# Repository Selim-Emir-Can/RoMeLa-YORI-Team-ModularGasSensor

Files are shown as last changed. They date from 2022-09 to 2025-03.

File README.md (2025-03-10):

# Modular Gas Sensor

## Table of Contents
* [Summary](#Summary)
* [Setup](#Setup)
* [Installation](#Installation)

## Summary
The Modular Gas Sensor uses 17 gas sensors that consist of:
<li>DFRobot CO2 Sensor V1.2</li>
<li>DHT22 Temperature and Humidity Sensor</li>
<li>DFRobot Ozone Sensor (0-10ppm) v1.0 (I2C)</li>
<li>DFRobot Gravity Formaldehyde (HCHO) Sensor (DAC)</li>
<li>SGP40 VOC (Volatile Organic Compound) Sensor (I2C)</li>
<li>Figaro TGS2611 Air Contaminants Sensor with drive board module</li>
<li>CJMCU-1100 MS-1100 VOC Gas Sensor Module Formaldehyde Benzene Gas Induction</li>
<li>MH-Z14 NDIR CO2 Infrared Sensor Module MH-Z14A Carbon Dioxide Sensor for CO2 (0-5000ppm, Serial Spot PWM)</li>
<li>MQ-2, MQ-3, MQ-4, MQ-5, MQ-6, MQ-7, MQ-8, MQ-9, MQ-135 Smoke Detection liquefied Methane Gas Sensor Module</li>

The data gathered from the sensors listed above during the cooking process will constitute a chemical signature which will be used to analyze the cumulative gas concentration with respect to time. The gas sensor shell stores these sensors, and the hardware which extracts and processes data which includes a custom PCB and a Raspberry Pi Zero 2W. All components of the gas sensor shell are modular, meaning it can be modified to store any amount of gas sensors if the necessary parts are made. More visual explanation can be found [here](https://selim-e-can.github.io/GasSensor.html).

## Setup

### SGP40 VOC Sensor and DFRobot Ozone Sensor (0-10ppm) v1.0
* enable I2C connection from settings using sudo raspi-config
* connect SDA to GPIO 2, SCL to GPIO 3

### DHT22 Digital Temperature and Humidity Sensor
* connect GPIO 4 pin to DAT pin

Note: The temperature sensor does not work according to specification if measurements are taken within a time interval less then 3 seconds.

### Other Gas Sensors
* connect rest of the gas sensors to MCP3008 ADC Converter channels

### First MCP3008 ADC Converter
* connect the GPIO 18 pin to Clock (CLK)
* connect the GPIO 23 pin to Master Input Slave Output (MISO)
* connect the GPIO 24 pin to Master Output Slave Input (MOSI)
* connect the GPIO 25 pin to Chip Select (CS)

### Second MCP3008 ADC Converter
* connect the GPIO 18 pin to Clock (CLK)
* connect the GPIO 23 pin to Master Input Slave Output (MISO)
* connect the GPIO 24 pin to Master Output Slave Input (MOSI)
* connect the GPIO 26 pin to Chip Select (CS)

## Installation
### Adafruit_GPIO Library
sudo apt-get update <br />
sudo apt-get install build-essential python-pip python-dev python-smbus git <br />
git clone https://github.com/adafruit/Adafruit_Python_GPIO.git <br />
cd Adafruit_Python_GPIO <br />
sudo python setup.py install <br />

### Adafruit_MCP3008 Library
sudo apt-get update <br />
sudo apt-get install build-essential python-dev python-smbus git <br />
cd ~ <br />
git clone https://github.com/adafruit/Adafruit_Python_MCP3008.git <br />
cd Adafruit_Python_MCP3008 <br />
sudo python setup.py install <br />

### DFRobot_Ozone Library
sudo apt-get update <br />
sudo apt-get upgrade <br />
git clone https://github.com/DFRobot/DFRobot_OzoneSensor <br />

### Adafruit_DHT Library
sudo pip3 install Adafruit_DHT

### smbus Library
sudo apt-get install python-smbus

### bcm2835 Library
wget http://www.airspayce.com/mikem/bcm2835/bcm2835-1.60.tar.gz <br />
tar zxvf bcm2835-1.60.tar.gz <br />
cd bcm2835-1.60/ <br />
sudo ./configure <br />
sudo make <br />
sudo make check <br />
sudo make install <br />

### wiringpi Library
sudo apt-get install wiringpi <br />
cd /tmp <br />
wget https://project-downloads.drogon.net/wiringpi-latest.deb <br />
sudo dpkg -i wiringpi-latest.deb <br />
gpio -v <br />

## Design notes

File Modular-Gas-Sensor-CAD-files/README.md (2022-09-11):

# Modular Gas Sensor

## Table of Contents
* [Summary](#Summary)
* [Setup](#Setup)

## Summary
Modular Gas Sensor uses 17 gas sensors within 4 layers:

 #### Layer 1 (M1 Chamber)
 <li>Flying Fish MQ-5 Sensor</li>
 <li>Flying Fish MQ-6 Sensor</li>
 <li>Flying Fish MQ-8 Sensor</li>
 <li>Flying Fish MQ-9 Sensor</li>
 <li>Flying Fish MQ-135 Sensor</li>
 
 #### Layer 2 (M2 Chamber)
 <li>Flying Fish MQ-2 Sensor</li>
 <li>Flying Fish MQ-3 Sensor</li>
 <li>Flying Fish MQ-4 Sensor</li>
 <li>Flying Fish MQ-7 Sensor</li>
 <li>Figaro TGS2611 Air Contaminants Sensor with drive board module</li>

 #### Layer 3 (M3 Chamber)
 
 <li>DHT22 Temperature and Humidity Sensor</li>
 <li>DFRobot CO2 Sensor V1.2</li>
 <li>MH-Z14 NDIR CO2 Infrared Sensor Module MH-Z14A Carbon Dioxide Sensor for CO2 (0-5000ppm, Serial Spot PWM)</li>
 <li>CJMCU-1100 MS-1100 VOC Gas Sensor Module Formaldehyde Benzene Gas Induction</li>

 #### Layer 4 (M4 Chamber)
 <li>DFRobot Ozone Sensor (0-10ppm) v1.0 (I2C)</li>
 <li>DFRobot Gravity Formaldehyde (HCHO) Sensor (DAC)</li>
 <li>SGP40 VOC (Volatile Organic Compound) Sensor (I2C)</li>

## Setup
For 3D printing a nozzle with a 6mm diameter was used at 30% infill for all parts. [Flexible coolant legs](https://www.digikey.com/en/products/detail/sparkfun-electronics/TOL-12783/5824155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), the [LCD Display](https://www.amazon.com/JANSANE-Arduino-Display-Interface-Raspberry/dp/B07D83DY17), and the [switch](https://www.amazon.com/gp/product/B01N2U8PK0/ref=ppx_yo_dt_b_search_asin_title?ie=UTF8&psc=1&pldnSite=1), and [buttons](https://www.amazon.com/gp/product/B06XF6PT9L/ref=ppx_yo_dt_b_search_asin_title?ie=UTF8&psc=1&pldnSite=1) that will be installed on the top cap were bought.

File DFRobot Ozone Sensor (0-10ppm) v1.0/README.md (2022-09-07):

# DFRobot Ozone Sensor (0-10ppm) v1.0

## Table of Contents
* [Summary](#Summary)
* [Setup](#Setup)
* [Installation](#Installation)

## Summary
The DFRobot Ozone Sensor (0-10ppm) v1.0 has a VCC pin, GND pin, SDA (Serial Data) pin, SCL (Serial Clock) pin and transmits data to the Raspberry Pi Zero 2W through the I2C communication protocol.

* DFRobot_Ozone.py defines the basic structure of the DFRobot_Ozone class, the implementation of the basic methods.
* get_ozone_data.py reads ozone concentration of one part per billion (PPB) using UART mode.

More documentation can be found [here](https://wiki.dfrobot.com/Gravity_IIC_Ozone_Sensor_(0-10ppm)%20SKU_SEN0321).

## Setup
* enable I2C connection from settings using sudo raspi-config
* connect SDA to GPIO 2, SCL to GPIO 3

## Installation
get_ozone_data.py uses the DFRobot_Ozone library which can be downloaded using:

### DFRobot_Ozone Library
sudo apt-get update <br />
sudo apt-get upgrade <br />
git clone https://github.com/DFRobot/DFRobot_OzoneSensor <br />

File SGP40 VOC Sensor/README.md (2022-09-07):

# SPG40 VOC (Volatile Organic Compound) Sensor

## Table of Contents
* [Summary](#Summary)
* [Setup](#Setup)
* [Installation](#Installation)

## Summary
SPG40 VOC Sensor has a VCC pin, GND pin, SDA (Serial Data) pin, SCL (Serial Clock) pin and transmits data to the Raspberry Pi Zero 2W through the I2C communication protocol. The SGP40.py file defines the basic structure of the SGP40 class, the implementation of the basic methods and prints. More documentation can be found [here](https://www.waveshare.com/wiki/SGP40_VOC_Sensor).

## Setup
* enable I2C connection from settings using sudo raspi-config
* connect SDA to GPIO 2, SCL to GPIO 3

## Installation
SGP40.py uses the smbus, bcm2835, and wiringpi libraries which can be downloaded using:

### smbus Library
sudo apt-get install python-smbus

### bcm2835 Library
wget http://www.airspayce.com/mikem/bcm2835/bcm2835-1.60.tar.gz <br />
tar zxvf bcm2835-1.60.tar.gz <br />
cd bcm2835-1.60/ <br />
sudo ./configure <br />
sudo make <br />
sudo make check <br />
sudo make install <br />

### wiringpi Library
sudo apt-get install wiringpi <br />
cd /tmp <br />
wget https://project-downloads.drogon.net/wiringpi-latest.deb <br />
sudo dpkg -i wiringpi-latest.deb <br />
gpio -v <br />

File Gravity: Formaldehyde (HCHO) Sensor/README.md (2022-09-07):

# Gravity: Formaldehyde (HCHO) Sensor

## Table of Contents
* [Summary](#Summary)
* [Setup](#Setup)
* [Installation](#Installation)

## Summary
The Gravity: Formaldehyde (HCHO) Sensor has a VCC pin, GND pin, and a data pin. The sensor has a DAC mode and a UART mode. Setting the Formaldehyde (HCHO) Sensor to DAC mode, using an MCP3008 ADC converter, a Raspberry Pi Zero 2W, and DFRobotHCHOSensor.py voltage data corrolated to ozone concentration can be displayed in real time. More documentation can be found [here](https://www.dfrobot.com/product-1574.html).

## Setup

### MCP3008 ADC Converter
* connect the GPIO 18 pin to Clock (CLK)
* connect the GPIO 23 pin to Master Input Slave Output (MISO)
* connect the GPIO 24 pin to Master Output Slave Input (MOSI)
* connect the GPIO 25 pin to Chip Select (CS)
* connect the data pin to Channel 0 input

## Installation
DFRobotHCHOSensor.py file uses the Adafruit_GPIO and Adafruit_MCP3008 libraries which can be downloaded using:

### Adafruit_GPIO Library
sudo apt-get update <br />
sudo apt-get install build-essential python-pip python-dev python-smbus git <br />
git clone https://github.com/adafruit/Adafruit_Python_GPIO.git <br />
cd Adafruit_Python_GPIO <br />
sudo python setup.py install <br />

### Adafruit_MCP3008 Library
sudo apt-get update <br />
sudo apt-get install build-essential python-dev python-smbus git <br />
cd ~ <br />
git clone https://github.com/adafruit/Adafruit_Python_MCP3008.git <br />
cd Adafruit_Python_MCP3008 <br />
sudo python setup.py install <br />

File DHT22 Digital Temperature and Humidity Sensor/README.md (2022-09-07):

# DHT22 Digital Temperature and Humidity Sensor

## Table of Contents
* [Summary](#Summary)
* [Setup](#Setup)
* [Installation](#Installation)

## Summary
The DHT22 Digital Temperature and Humidity Sensor has a DAT (Data) pin, a VCC pin, and a GND pin.
Temp-sensor.py file prints the temperature and humidity readings to the terminal every 3 seconds.
More documentation can be found [here](https://www.sparkfun.com/datasheets/Sensors/Temperature/DHT22.pdf).

## Setup
* connect GPIO 4 pin to DAT pin

Note: The temperature sensor does not work according to specification if measurements are taken within a time interval less then 3 seconds.

## Installation
Temp-sensor.py file uses the Adafruit_DHT library which can be downloaded using:

sudo pip3 install Adafruit_DHT

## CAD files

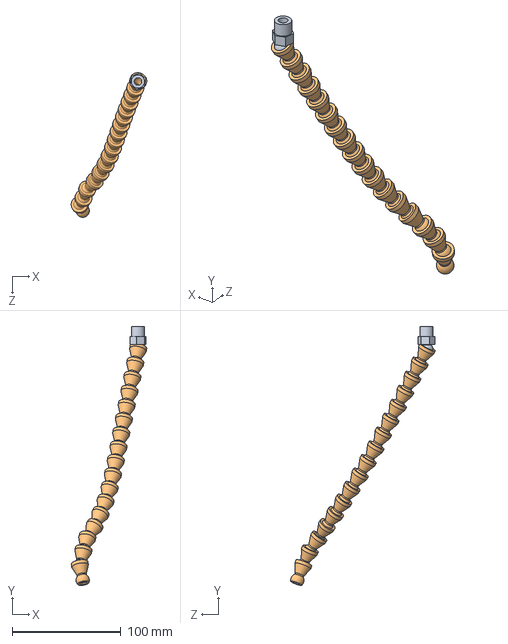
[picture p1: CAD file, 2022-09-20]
Modular-Gas-Sensor-CAD-files/Flexible coolant.SLDASM
69.7 x 238.7 x 133.4 mm
Flexible coolant conexion
Flexible coolant x 17

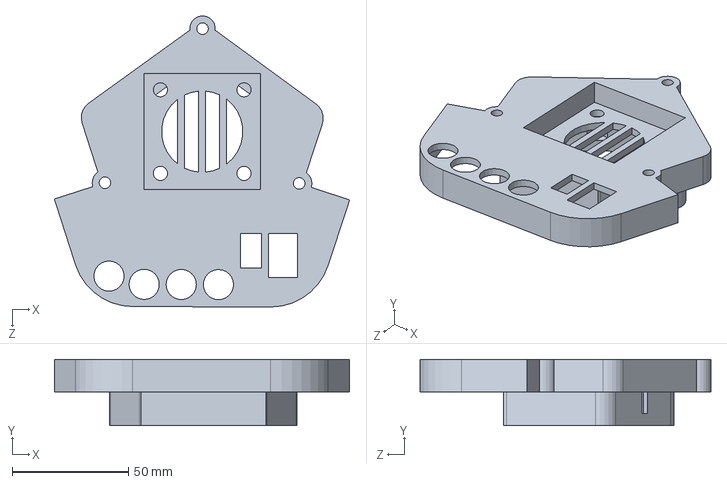
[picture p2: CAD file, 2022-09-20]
Modular-Gas-Sensor-CAD-files/topCap.SLDPRT
127.2 x 28.4 x 125.3 mm

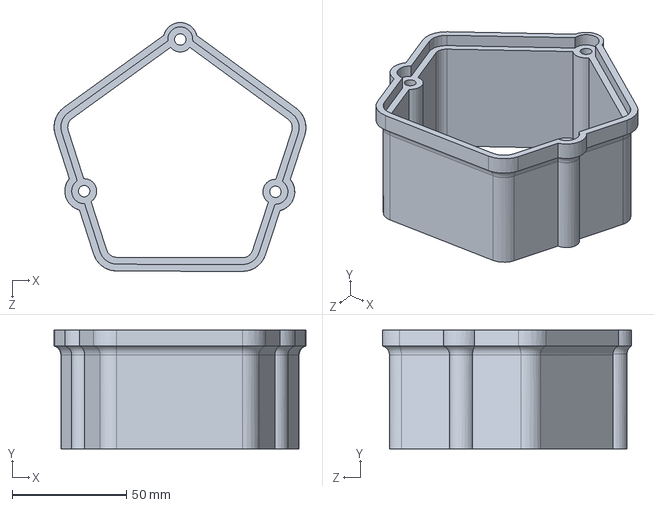
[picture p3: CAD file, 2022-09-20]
Modular-Gas-Sensor-CAD-files/shell-2nd.SLDPRT
110.2 x 52.0 x 108.9 mm

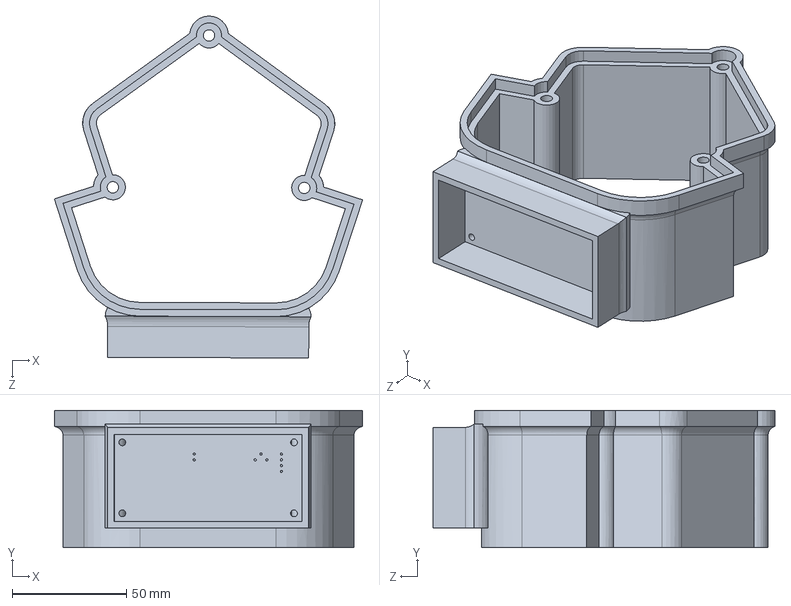
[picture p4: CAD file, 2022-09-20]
Modular-Gas-Sensor-CAD-files/big-shell.SLDPRT
134.7 x 60.0 x 149.5 mm

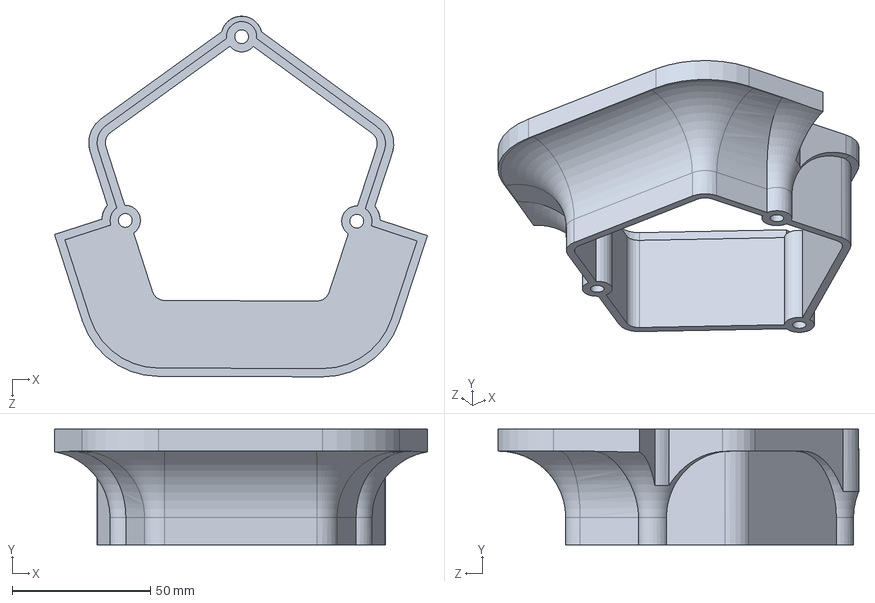
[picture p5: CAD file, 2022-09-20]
Modular-Gas-Sensor-CAD-files/transition.SLDPRT
134.7 x 41.8 x 130.3 mm

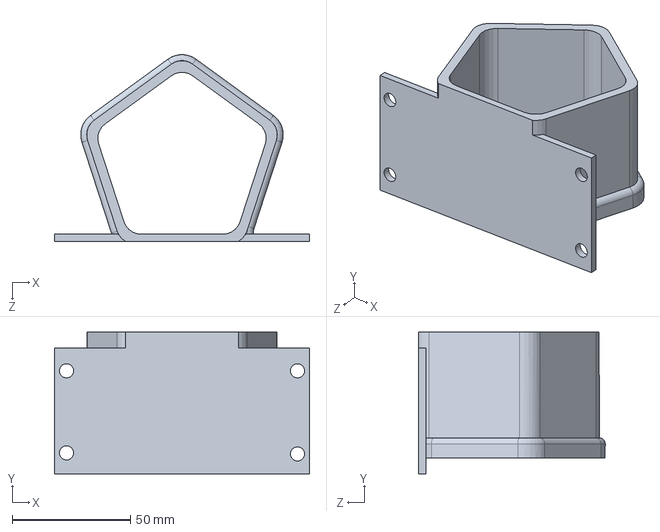
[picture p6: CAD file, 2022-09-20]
Modular-Gas-Sensor-CAD-files/RaspBerryPi.SLDPRT
108.0 x 60.1 x 79.0 mm

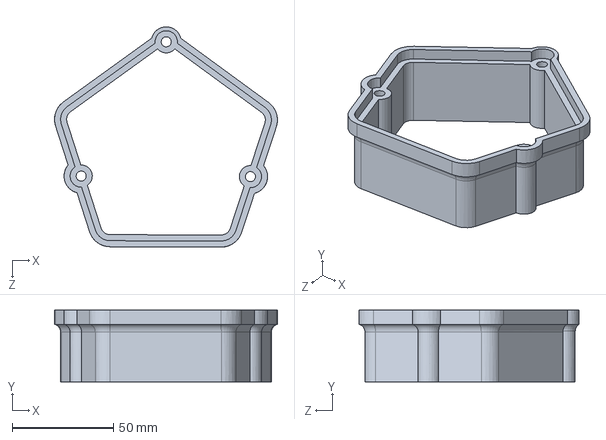
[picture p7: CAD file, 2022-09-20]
Modular-Gas-Sensor-CAD-files/shell.SLDPRT
110.2 x 35.5 x 108.9 mm

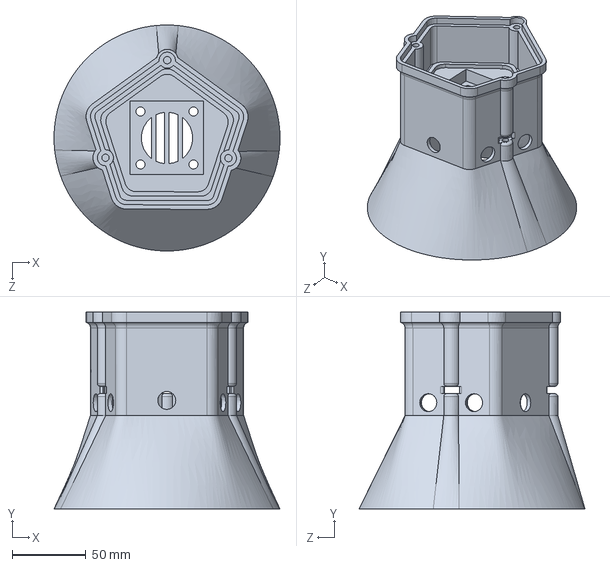
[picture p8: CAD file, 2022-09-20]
Modular-Gas-Sensor-CAD-files/bottomCap.SLDPRT
153.7 x 133.9 x 153.7 mm

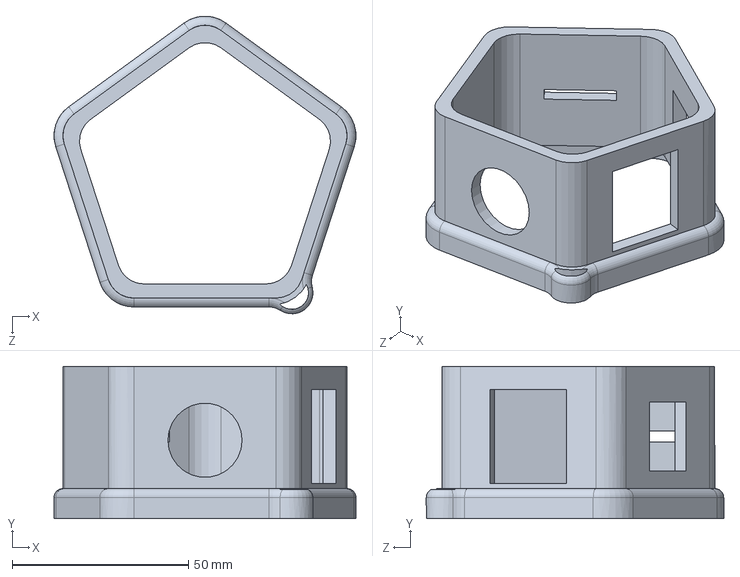
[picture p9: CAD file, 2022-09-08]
Modular-Gas-Sensor-CAD-files/GS-M4.SLDPRT
85.8 x 43.2 x 84.5 mm

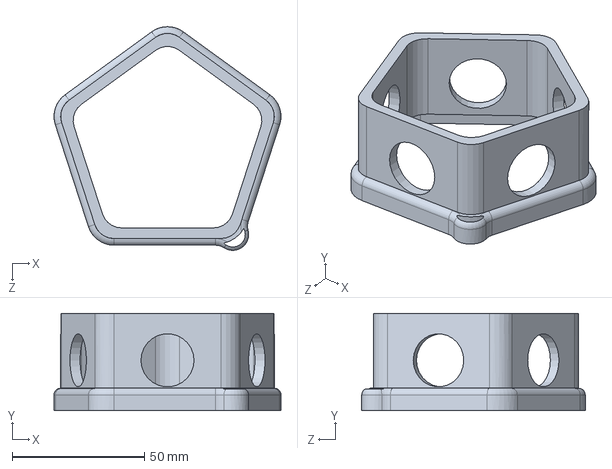
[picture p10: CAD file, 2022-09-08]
Modular-Gas-Sensor-CAD-files/GS-M1.SLDPRT
85.8 x 36.8 x 84.5 mm

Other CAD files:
Modular-Gas-Sensor-CAD-files/smt_resistor101.STEP.SLDPRT
Modular-Gas-Sensor-CAD-files/lcd window.STEP.SLDPRT
Modular-Gas-Sensor-CAD-files/pcbboard.STEP.SLDPRT
Modular-Gas-Sensor-CAD-files/16pin_header__.STEP.SLDPRT
Modular-Gas-Sensor-CAD-files/backlight.STEP.SLDPRT
Modular-Gas-Sensor-CAD-files/smt_resistor222.x_t.SLDPRT
Modular-Gas-Sensor-CAD-files/i2c board.STEP.SLDPRT
Modular-Gas-Sensor-CAD-files/conductor.STEP.SLDPRT
Modular-Gas-Sensor-CAD-files/Flexible coolant conexion.SLDPRT
Modular-Gas-Sensor-CAD-files/Flexible coolant.SLDPRT
Modular-Gas-Sensor-CAD-files/GS-M2.SLDPRT
Modular-Gas-Sensor-CAD-files/GS-M3.SLDPRT
Modular-Gas-Sensor-CAD-files/liquid crystal grabcad i2s.STEP.SLDPRT

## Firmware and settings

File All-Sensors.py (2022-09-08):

import Adafruit_GPIO.SPI as SPI
import Adafruit_MCP3008
import sys
import numpy as np
import csv
import time
sys.path.append("../")
from DFRobot_Ozone import *
import math
import struct
import smbus
import Adafruit_DHT

DHT_SENSOR = Adafruit_DHT.DHT22
DHT_PIN = 4
# import ctypes

COLLECT_NUMBER   = 20              # collect number, the collection range is 1-100
IIC_MODE         = 0x01            # default use IIC1

'''
   The first  parameter is to select i2c0 or i2c1
   The second parameter is the i2c device address
   The default address for i2c is OZONE_ADDRESS_3
      OZONE_ADDRESS_0        0x70
      OZONE_ADDRESS_1        0x71
      OZONE_ADDRESS_2        0x72
      OZONE_ADDRESS_3        0x73
'''
ozone = DFRobot_Ozone_IIC(IIC_MODE ,OZONE_ADDRESS_3)
'''
  The module is configured in automatic mode or passive
    MEASURE_MODE_AUTOMATIC  active  mode
    MEASURE_MODE_PASSIVE    passive mode
'''
ozone.set_mode(MEASURE_MODE_AUTOMATIC)
#####################################################################################################################################################################################
# voc = ctypes.cdll.LoadLibrary('./voclib.so')

SGP40_CMD_FEATURE_SET = [0x20, 0x2F]
SGP40_CMD_MEASURE_TEST = [0X28,0X0E]
SGP40_CMD_SOFT_RESET = [0X00,0X06]
SGP40_CMD_HEATER_OFF = [0X36,0X15]
SGP40_CMD_MEASURE_RAW = [0X26,0X0F]
# SGP40_CMD_GET_SERIAL_ID = [0X36,0X82] #DATASHEET is not written ,but Sensirion have


CRC_TABLE = [
        0, 49, 98, 83, 196, 245, 166, 151, 185, 136, 219, 234, 125, 76, 31, 46,
        67, 114, 33, 16, 135, 182, 229, 212, 250, 203, 152, 169, 62, 15, 92, 109,
        134, 183, 228, 213, 66, 115, 32, 17, 63, 14, 93, 108, 251, 202, 153, 168,
        197, 244, 167, 150, 1, 48, 99, 82, 124, 77, 30, 47, 184, 137, 218, 235,
        61, 12, 95, 110, 249, 200, 155, 170, 132, 181, 230, 215, 64, 113, 34, 19,
        126, 79, 28, 45, 186, 139, 216, 233, 199, 246, 165, 148, 3, 50, 97, 80,
        187, 138, 217, 232, 127, 78, 29, 44, 2, 51, 96, 81, 198, 247, 164, 149,
        248, 201, 154, 171, 60, 13, 94, 111, 65, 112, 35, 18, 133, 180, 231, 214,
        122, 75, 24, 41, 190, 143, 220, 237, 195, 242, 161, 144, 7, 54, 101, 84,
        57, 8, 91, 106, 253, 204, 159, 174, 128, 177, 226, 211, 68, 117, 38, 23,
        252, 205, 158, 175, 56, 9, 90, 107, 69, 116, 39, 22, 129, 176, 227, 210,
        191, 142, 221, 236, 123, 74, 25, 40, 6, 55, 100, 85, 194, 243, 160, 145,
        71, 118, 37, 20, 131, 178, 225, 208, 254, 207, 156, 173, 58, 11, 88, 105,
        4, 53, 102, 87, 192, 241, 162, 147, 189, 140, 223, 238, 121, 72, 27, 42,
        193, 240, 163, 146, 5, 52, 103, 86, 120, 73, 26, 43, 188, 141, 222, 239,
        130, 179, 224, 209, 70, 119, 36, 21, 59, 10, 89, 104, 255, 206, 157, 172
        ]

#Without_humidity_compensation
#sgp40_measure_raw + 2*humi + CRC + 2*temp + CRC
WITHOUT_HUM_COMP = [0X26, 0X0F, 0X80, 0X00, 0XA2, 0X66, 0X66, 0X93] # default Temperature=25 Humidity=50
WITH_HUM_COMP = [0x26, 0x0f, 0x00, 0x00, 0x00, 0x00, 0x00, 0x00] #Manual input

ADDR = 0x59

class SGP40:
    def __init__(self, address=ADDR):
        self.i2c = smbus.SMBus(1)
        self.address = address

        # feature set 0x3220
        self.write(SGP40_CMD_FEATURE_SET)
        time.sleep(0.25)
        Rbuf = self.Read()
        print('feature set:%#x'% ((int(Rbuf[0]) << 8) | Rbuf[1]))
        if ((int(Rbuf[0]) << 8) | Rbuf[1]) != 0x3220:
            raise RuntimeError("Self test failed")

        # Self Test 0xD400
        self.write(SGP40_CMD_MEASURE_TEST)
        time.sleep(0.25)
        Rbuf = self.Read()
        print('Self Test  :%#x'% ((int(Rbuf[0]) << 8) | Rbuf[1]))
                if ((int(Rbuf[0]) << 8) | Rbuf[1]) != 0xD400: #0x4B00 is failed,0xD400 pass
            raise RuntimeError("Self test failed")

        # reset
        # self.write(SGP40_CMD_SOFT_RESET)

    def Read(self):
        return self.i2c.read_i2c_block_data(self.address, 0, 3)#last byte is CRC8

    def write(self, cmd):
        self.i2c.write_byte_data(self.address, cmd[0], cmd[1])

    def write_block(self, cmd):
        self.i2c.write_i2c_block_data(self.address, cmd[0], cmd[1:8])

    def raw(self):
        """The raw gas value"""
        # recycle a single buffer
        self.write_block(WITHOUT_HUM_COMP)
        time.sleep(0.25)
        Rbuf = self.Read()
        return ((int(Rbuf[0]) << 8) | Rbuf[1])

    def measureRaw(self, temperature, humidity):
        # 2*humi + CRC
        #paramh = struct.pack(">H", math.ceil(humidity * 0xffff / 100))
        h = humidity * 0xffff // 100
        paramh = (h >> 8, h & 0xff)
        crch = self.__crc(paramh[0], paramh[1])

        # 2*temp + CRC
        #paramt = struct.pack(">H", math.ceil((temperature + 45) * 0xffff / 175))
        t = (temperature + 45) * 0xffff // 175
        paramt = (t >> 8, t & 0xff)
        crct = self.__crc(paramt[0], paramt[1])

        WITH_HUM_COMP[2:3] = paramh
        WITH_HUM_COMP[4] = int(crch)
        WITH_HUM_COMP[5:6] = paramt
        WITH_HUM_COMP[7] = int(crct)
        #print(WITH_HUM_COMP)
        self.write_block(WITH_HUM_COMP)

        time.sleep(0.03)
        Rbuf = self.Read()
        # print(Rbuf)
                return ((int(Rbuf[0]) << 8) | Rbuf[1])

    def __crc(self, msb, lsb):
        crc = 0xff
        crc ^= msb
        crc = CRC_TABLE[crc]
        if lsb is not None:
            crc ^= lsb
            crc = CRC_TABLE[crc]
        return crc
 #######################################################################################################################
system_voltage = 5
resolution = 1024
#1st ADC Converter Config
CLK = 11 # gpio 18 on rpi 3
MISO = 9 # gpio 23 on rpi 3
MOSI = 10 # gpio 24 on rpi 3
CS = 8 # gpio 25 on rpi 3
CS2 = 7 # gpio 26 on rpi 3
mcp = Adafruit_MCP3008.MCP3008(clk=CLK, cs=CS, miso=MISO, mosi=MOSI)
mcp2 = Adafruit_MCP3008.MCP3008(clk=CLK, cs=CS2, miso=MISO, mosi=MOSI)
def PPM_Reading(reading):
    return(3.125*reading - 1.25)

def Analog_Read(ADC_Reading):
  return(ADC_Reading*(system_voltage/resolution))

#Convert Analog Data to Digital Data and store it in an np array
print('Reading MCP3008 values, press Ctrl-C to quit...')
# Print nice channel column headers.
print('| {0:>4} | {1:>4} | {2:>4} | {3:>4} | {4:>4} | {5:>4} | {6:>4} | {7:>4} | {8:>4} | {9:>4} | {10:>4} | {11:>4} | {12:>4} | {13:>4} | {14:>4} | {15:>4} | {16:>4} | {17:>4} |'.format(*range(18)))
print('-' * 57)
rows, cols = (1, 18) # 1 x 16 vector for two ADC conververters of size 8 and 2 other sensors
arr = np.zeros((rows, cols))

def createCSVfile(arr):
    path_to_csv_file = '/home/pi/DFRobot_OzoneSensor-master/python/raspberrypi/examples/AllSensor.csv' #path to csv file
    f = open(path_to_csv_file, 'w')
    writer = csv.writer(f)
    writer.writerows(arr)
    f.close()
# can also use for ozone sensor print("Raw Gas: ", sgp.raw())
#  print("measureRaw Gas: %d" %arr_voc [np.size(arr)-1])
#  print("Ozone concentration is %d PPB."%arr_oz[np.size(arr) - 1])
#  time.sleep(1)

import RPi.GPIO as GPIO
GPIO.setmode(GPIO.BCM)     # set up BCM GPIO numbering
GPIO.setup(23, GPIO.IN)
#############################################################################
if __name__ == '__main__':
    sgp = SGP40()
    while(GPIO.input(23) == 0):
        # Read all the ADC channel values in an np array.
        humidity, temperature = Adafruit_DHT.read(DHT_SENSOR, DHT_PIN)
        if humidity is not None and temperature is not None:
            # print("Temp={0:0.1f}C Humidity={1:0.1f}%".format(temperature, humidity), ozone.get_ozone_data(COLLECT_NUMBER), sgp.measureRaw(25, 50))
            arr = np.append(arr, [
                [PPM_Reading(mcp.read_adc(0)), Analog_Read(mcp.read_adc(1)), Analog_Read(mcp.read_adc(2)),
                 Analog_Read(mcp.read_adc(3)), Analog_Read(mcp.read_adc(4)), Analog_Read(mcp.read_adc(5)),
                 PPM_Reading(mcp2.read_adc(0)), Analog_Read(mcp2.read_adc(1)), Analog_Read(mcp2.read_adc(2)),
                 Analog_Read(mcp2.read_adc(3)), Analog_Read(mcp2.read_adc(4)), Analog_Read(mcp2.read_adc(5)),
                 Analog_Read(mcp2.read_adc(6)), Analog_Read(mcp2.read_adc(7)), ozone.get_ozone_data(COLLECT_NUMBER),
                 sgp.measureRaw(25, 50), temperature, humidity]], axis=0)
            k = np.size(arr, axis=0) - 1
            print('| ', arr[k, 0], ' | ', arr[k, 1], ' | ', arr[k, 2], ' | ', arr[k, 3], ' | ', arr[k, 4], ' | ',
                  arr[k, 5], ' | ', arr[k, 6], ' | ', arr[k, 7], ' | ', arr[k, 8], ' | ', arr[k, 9], ' | ',
                  arr[k, 10], ' | ', arr[k, 11], ' | ', arr[k, 12], ' | ', arr[k, 13], ' | ', arr[k, 14], ' | ',
                  arr[k, 15], ' | ', arr[k, 16], ' | ', arr[k, 17], ' |')  # ,arr[k,18],' |')
        else:
            print("failure");
        time.sleep(3)
    print(np.size(arr))
    arr = np.delete(arr, 0, 0)
    createCSVfile(arr)
